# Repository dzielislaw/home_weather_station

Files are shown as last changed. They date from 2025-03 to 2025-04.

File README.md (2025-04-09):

# home-weather-station
## English
This home weather station is a STM32 microcontroller-based device. It performs measurements such as:
 - indor temperature
 - outdoor temperature via external wired probe
 - atmospheric pressure
 - air humidity
 - PM (Particulate Matter) concentration
and moreover it alarms of presence of flammable gases such as propane or buthane.

https://github.com/user-attachments/assets/9bdbaac8-06a2-42ca-afe4-3092634e5976

## Polski
Projekt domowej stacji pogody oparty o wykorzystanie mikrokontrolera STM32G491RE. Wykonuje pomiary takie jak:
- temperatura wewnętrzna
- temperatura zewnętrzna
- ciśnienie atmosferyczne
- wilgotność powietrza
- stężenie pyłu zawieszonego PM1, PM2,5 oraz PM10 (jakości powietrza).
  
ilustracja

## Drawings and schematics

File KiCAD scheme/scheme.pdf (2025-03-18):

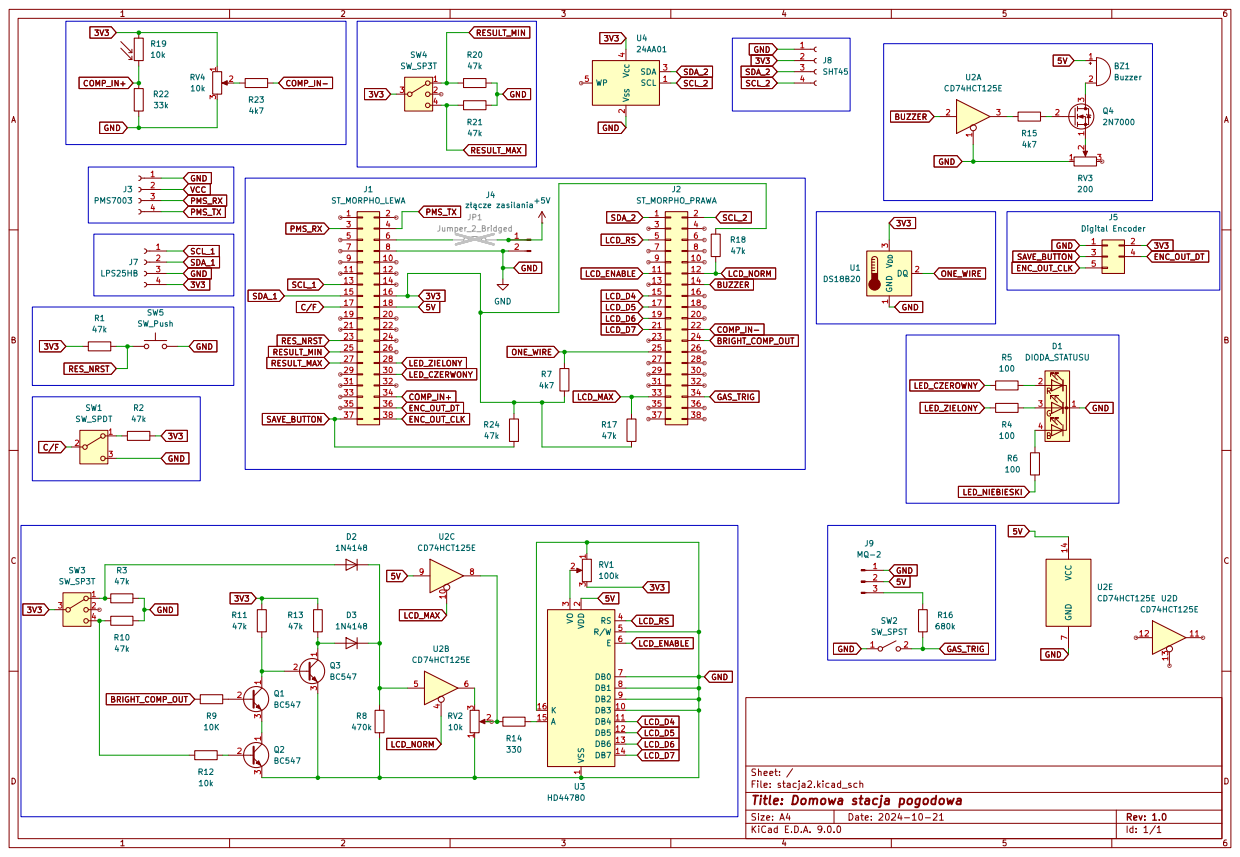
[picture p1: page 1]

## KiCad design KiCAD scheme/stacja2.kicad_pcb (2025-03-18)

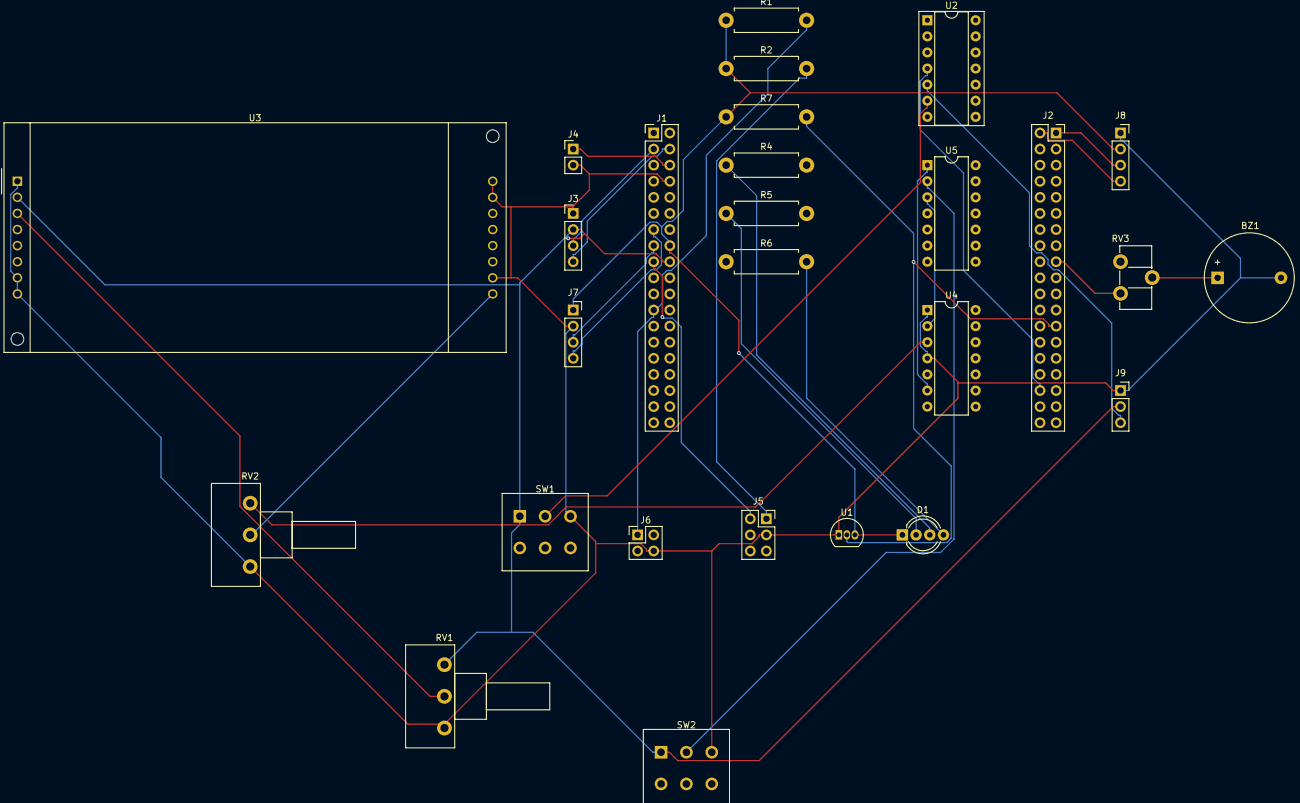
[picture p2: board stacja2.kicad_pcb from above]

Board: 2 copper layers, 27 parts (0 on the bottom side), 36 nets.

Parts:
BZ1: Buzzer; Buzzer_D14mm_H7mm_P10mm
D1: DIODA_STATUSU; LED_D5.0mm-4_RGB_Wide_Pins
J1: ST_MORPHO_LEWA; PinHeader_2x19_P2.54mm_Vertical
J2: ST_MORPHO_PRAWA; PinSocket_2x19_P2.54mm_Vertical
J3: PMS7003; PinHeader_1x04_P2.54mm_Vertical
J4: złącze zasilania; PinHeader_1x02_P2.54mm_Vertical
J5: CELSIUS_FAHRENEIT_SWITCH; PinSocket_2x03_P2.54mm_Vertical
J6: RESET_TACT_SWITCH; PinHeader_2x02_P2.54mm_Vertical
J7: LPS25HB; PinSocket_1x04_P2.54mm_Vertical
J8: SHT35; PinSocket_1x04_P2.54mm_Vertical
J9: MQ-2; PinSocket_1x03_P2.54mm_Vertical
R1, R2: 47k; R_Axial_DIN0411_L9.9mm_D3.6mm_P12.70mm_Horizontal
R4, R5, R6: 460; R_Axial_DIN0411_L9.9mm_D3.6mm_P12.70mm_Horizontal
R7: 4k7; R_Axial_DIN0411_L9.9mm_D3.6mm_P12.70mm_Horizontal
RV1, RV2: 100k; Potentiometer_Piher_T-16H_Single_Horizontal
RV3: 200; Potentiometer_ACP_CA9-H5_Horizontal
SW1, SW2: SW_SPDT; SW_PUSH_E-Switch_FS5700DP_DPDT
U1: DS18B20; TO-92_Inline
U2: 4081; DIP-14_W7.62mm_Socket
U3: HD44780; NHD-0420H1Z
U4: 74AHCT125; DIP-14_W7.62mm
U5: 4071; DIP-14_W7.62mm

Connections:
3V3: D1.1 (A), J1.16, J7.4, J8.2, R1.1, R2.1, R7.1, U1.3 (V_{DD})
5V: J1.18, RV1.3, SW1.1 (A), SW2.1 (A), U3.2 (VDD)
+5V: J1.6, J4.1
BUZZER+: J2.14, RV3.3
C/F: J1.17, J5.2
GAS_TRIG: J2.34, U2.4
GND: BZ1.2 (-), J1.8, J3.1, J4.2, J5.3, J6.4, J7.3, J8.1, J9.1, RV1.1, RV2.1, SW1.3 (C), SW2.3 (C), U1.1 (GND), U3.1 (VSS), U3.5 (R/W), U3.7 (DB0), U3.8 (DB1), U3.9 (DB2), U3.10 (DB3), U3.15 (A), U4.1, U4.4
LCD_D4: J2.15, U3.11 (DB4)
LCD_D5: J2.17, U3.12 (DB5)
LCD_D6: J2.19, U3.13 (DB6)
LCD_D7: J2.21, U3.14 (DB7)
LCD_ENABLE: J2.11, U3.6 (E)
LCD_RS: J2.5, U3.4 (RS)
LED_ZIELONY: J1.28, R4.2
unnamed: BZ1.1 (+), RV3.2
unnamed: D1.4 (BK), R6.2
unnamed: D1.3 (GK), R4.1
unnamed: D1.2 (RK), R5.1
unnamed: J5.1, R2.2
unnamed: J9.3, U2.5
unnamed: RV2.3, U4.3
unnamed: SW1.2 (B), U2.6
unnamed: SW2.2 (B), U5.2
unnamed: RV2.2, U3.16 (K)
unnamed: RV1.2, U3.3 (VO)
unnamed: U4.2, U5.3
unnamed: U4.6, U5.1
ONE_WIRE: J2.25, R7.2, U1.2 (DQ)
PMS_RX: J1.3, J3.3
PMS_TX: J1.4, J3.4
RES_NRST: J1.23, J6.1, R1.2
SCL_1: J1.13, J7.1
SCL_2: J2.2, J8.4
SDA_1: J1.15, J7.2
SDA_2: J2.1, J8.3
VCC: J3.2, J9.2

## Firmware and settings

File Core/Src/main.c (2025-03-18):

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
/* Includes ------------------------------------------------------------------*/
#include "main.h"
#include "comp.h"
#include "dac.h"
#include "i2c.h"
#include "rtc.h"
#include "tim.h"
#include "usart.h"
#include "gpio.h"

/* USER CODE BEGIN Includes */
#include <string.h>
#include <stdio.h>
#include <stdbool.h>
#include "exti.h"
#include "LPS25HB.h"
#include "SHT45.h"
#include "PMS7003.h"
#include "ILI9341.h"
#include "HD44780.h"
#include "RGB565.h"
#include "EPaper.h"
#include "OneWire.h"
#include "DS18B20.h"
#include "EEPROM_24AA01.h"
#include "units.h"
/* USER CODE END Includes */

/* USER CODE BEGIN PTD */
typedef union
{
  int16_t altitude;
  uint8_t memoryImage[2];
} altitudeUnion;

/* USER CODE END PTD */


/* USER CODE BEGIN PV */
 Measurements measurements;
 float tempFromSHT35;
  
bool isWarmingUp = true;
bool isFirstInterrupt = true;
bool shouldLightUpAlarmLED = false;
bool shouldUpdateEeprom = false;
bool shouldEnbleNormBrightness = false;
bool shoulEnable_maxBrightness = false;
bool shouldDelay = true;
bool isPM10Last = true;
altitudeUnion altitude;
/* USER CODE END PV */

void SystemClock_Config(void);
/* USER CODE BEGIN PFP */
void updateMinMaxF(float* value, float* min, float* max);
void updateMinMax(uint16_t* value, uint16_t* min, uint16_t* max);
/* USER CODE END PFP */

/* USER CODE BEGIN 0 */
void handleTimer3PeriodElapsed()
{
  if(isFirstInterrupt == true)
   {
     isFirstInterrupt = false;
   }
   else
   {
     HAL_TIM_Base_Stop_IT(&htim3);
     const char* communicate = "DEBUG: Gas sensor warmed up\r\n";
     HAL_UART_Transmit(&huart4, communicate, strlen(communicate), HAL_MAX_DELAY);
     HAL_GPIO_EXTI_Callback(GPIO_PIN_4);
   }
}

void handleTimer7PeriodElapsed()
{
  if(shouldLightUpAlarmLED == true)
   {
     HAL_TIM_PWM_Start(&htim2, TIM_CHANNEL_2);
     shouldLightUpAlarmLED = false;
   }
   else
   {
     HAL_TIM_PWM_Stop(&htim2, TIM_CHANNEL_2);
     shouldLightUpAlarmLED = true;
   }
}

void HAL_TIM_PeriodElapsedCallback(TIM_HandleTypeDef* htim)
{
  if(htim == &htim3) handleTimer3PeriodElapsed();
  else if(htim == &htim7) handleTimer7PeriodElapsed();
}

void updateMinMaxF(float* value, float* min, float* max)
{
    if(*min > *value) *min = *value;
    if(*max < *value) *max = *value;
}

void updateMinMax(uint16_t* value, uint16_t* min, uint16_t* max)
{
    if(*min > *value) *min = *value;
    if(*max < *value) *max = *value;
}

void convertMeasurementsToCelsius()
{
    measurements.tempUnit = CELSIUS;
    convertFahrenheitToCelsius(&measurements.outdoorTemp);
    convertFahrenheitToCelsius(&tempFromSHT35);
    convertFahrenheitToCelsius(&measurements.temp);
    convertFahrenheitToCelsius(&measurements.minTemp);
    convertFahrenheitToCelsius(&measurements.maxTemp);
    convertFahrenheitToCelsius(&measurements.maxOutdoorTemp);
    convertFahrenheitToCelsius(&measurements.minOutdoorTemp);
}

void convertMeasurementsToFahrenheit()
{
  measurements.tempUnit = FAHRENHEIT;
  convertCelsiusToFahrenheit(&measurements.outdoorTemp);
  convertCelsiusToFahrenheit(&tempFromSHT35);
  convertCelsiusToFahrenheit(&measurements.temp);
  convertCelsiusToFahrenheit(&measurements.minTemp);
  convertCelsiusToFahrenheit(&measurements.maxTemp);
  convertCelsiusToFahrenheit(&measurements.maxOutdoorTemp);
  convertCelsiusToFahrenheit(&measurements.minOutdoorTemp);
}

/* USER CODE END 0 */

/**
  * @brief  The application entry point.
  * @retval int
  */
int main(void)
{

  /* USER CODE BEGIN 1 */
  altitudeUnion tmp;
  /* USER CODE END 1 */

  /* MCU Configuration--------------------------------------------------------*/

  /* Reset of all peripherals, Initializes the Flash interface and the Systick. */
  HAL_Init();

  /* Configure the system clock */
  SystemClock_Config();

  /* Initialize all configured peripherals */
  MX_GPIO_Init();
  MX_UART4_Init();
  MX_I2C1_Init();
  MX_I2C3_Init();
  MX_RTC_Init();
  MX_UART5_Init();
  MX_DAC1_Init();
  MX_TIM2_Init();
  MX_TIM3_Init();
  MX_USART3_UART_Init();
  MX_TIM4_Init();
  MX_TIM7_Init();
  MX_COMP4_Init();
  MX_TIM1_Init();
  MX_TIM20_Init();
  /* USER CODE BEGIN 2 */
  oneWire_HandleTypeDef* hOneWire = &huart3;
  oneWireReset(hOneWire);
  HAL_GPIO_EXTI_Callback(GPIO_PIN_13);
  /* USER CODE END 2 */

  /* Infinite loop */
  /* USER CODE BEGIN WHILE */
  
  //HAL_GPIO_WritePin(LCD_BRIGHT_NORM_GPIO_Port, LCD_BRIGHT_NORM_Pin, GPIO_PIN_RESET);
  
  char communicate[256];
  char unit[5];

  uint32_t brightnessState;
  measurements.tempUnit = CELSIUS;
  
  RTC_DateTypeDef date;
  RTC_TimeTypeDef time;
  
  EEPROM_24AA01_HandleTypeDef eeprom;
  strcpy(eeprom.name, "i2c eeprom");
  eeprom.bus = &hi2c3;
  
  SHT45_HandleTypeDef sht45_Sensor;
  strcpy(sht45_Sensor.name, "indoor humidity sensor");
  sht45_Sensor.bus = &hi2c3;
  
  LPS25HB_HandleTypeDef lps25hb_Sensor;
  strcpy(lps25hb_Sensor.name, "indoor pressure sensor");
  lps25hb_Sensor.bus = &hi2c1;
  lps25hb_Sensor.sensorAltitude = altitude.altitude;
  
  PMS7003_HandleTypeDef pms7003_Sensor;
  strcpy(pms7003_Sensor.name, "indoor air pollution sensor");
  pms7003_Sensor.bus = &huart5;

  DS18B20_HandleTypeDef ds18b20_Sensor;
  strcpy(ds18b20_Sensor.name, "outdoor temperature sensor");
  ds18b20_Sensor.bus = hOneWire;
  uint8_t romCode[] = {0x28, 0x7e, 0x4c, 0x14, 0x00, 0x00, 0x00, 0x6b};
  for(uint8_t i = 0 ; i < 8; i++)
  {
    ds18b20_Sensor.idNumber[i] = romCode[i];
  }
  
  
  HAL_TIM_Base_Start(&htim2);
  HAL_TIM_PWM_Start(&htim2, TIM_CHANNEL_1);
  HAL_TIM_PWM_Start(&htim2, TIM_CHANNEL_2);
  HAL_TIM_Base_Start_IT(&htim3);
  
  HAL_TIM_Encoder_Start(&htim1, TIM_CHANNEL_ALL);
  EEPROM_24AA01_ReadByte(&eeprom, 0x40, &altitude.memoryImage[0]);
  EEPROM_24AA01_ReadByte(&eeprom, 0x41, &altitude.memoryImage[1]);
  __HAL_TIM_SET_COUNTER(&htim1, altitude.altitude * 2);
   
   
  sprintf(communicate, "Weather station hello!\r\n");
  HAL_UART_Transmit(&huart4, communicate, strlen(communicate), HAL_MAX_DELAY);
  SHT45_init(&sht45_Sensor);
  sprintf(communicate, "SHT45 initialization... OK\r\n");
  HAL_UART_Transmit(&huart4, communicate, strlen(communicate), HAL_MAX_DELAY);
  
  if(LPS25HB_init(&lps25hb_Sensor) == -1)
  {
    sprintf(communicate, "LPS25HB pressure sensor initliazation... FAILED\r\n");
    HAL_UART_Transmit(&huart4, communicate, strlen(communicate), HAL_MAX_DELAY);
  }
  else
  {
    sprintf(communicate, "LPS25HB pressure sesnsor initialization... OK\r\n");
    HAL_UART_Transmit(&huart4, communicate, strlen(communicate), HAL_MAX_DELAY);
  }
  
  HD44780_Pin d4;
  d4.Port = LCD_D4_GPIO_Port;
  d4.Pin = LCD_D4_Pin;
  
  HD44780_Pin d5;
  d5.Port = LCD_D5_GPIO_Port;
  d5.Pin = LCD_D5_Pin;
  
  HD44780_Pin d6;
  d6.Port = LCD_D6_GPIO_Port;
  d6.Pin = LCD_D6_Pin;
  
  HD44780_Pin d7;
  d7.Port = LCD_D7_GPIO_Port;
  d7.Pin = LCD_D7_Pin;
  
  HD44780_Pin rs;
  rs.Port = LCD_RS_GPIO_Port;
  rs.Pin = LCD_RS_Pin;
  
  HD44780_Pin enable;
  enable.Port = LCD_ENABLE_GPIO_Port;
  enable.Pin = LCD_ENABLE_Pin;
  
  HD44780_HandleTypeDef hHD44780;
  hHD44780.D4 = d4;
  hHD44780.D5 = d5;
  hHD44780.D6 = d6;
  hHD44780.D7 = d7;
  hHD44780.RS = rs;
  hHD44780.Enable = enable;
  
  HD44780_Init(&hHD44780);
  
  sprintf(communicate, "HD44780 initialization (master only) DONE\r\n");
  HAL_UART_Transmit(&huart4, communicate, strlen(communicate), HAL_MAX_DELAY);
  HAL_GPIO_WritePin(LCD_BRIGHT_NORM_GPIO_Port, LCD_BRIGHT_NORM_Pin, GPIO_PIN_RESET);
  
  char lcdString[21];
  HAL_COMP_Start(&hcomp4);
  HAL_DAC_Start(&hdac1, DAC_CHANNEL_1);
   HAL_DAC_SetValue(&hdac1, DAC_CHANNEL_1, DAC_ALIGN_12B_R, 02570); // dobrane empirycznie
  while (1)
  {         
    brightnessState = HAL_COMP_GetOutputLevel(&hcomp4);
    //HAL_COMP_Stop(&hcomp4);
    //HAL_DAC_Stop(&hdac1, DAC_CHANNEL_1);
    PMS7003_getResults(&pms7003_Sensor, &measurements.pm1_0, &measurements.pm2_5, &measurements.pm10);
    updateMinMax(&measurements.pm1_0, &measurements.minPm1_0, &measurements.maxPm1_0);
      updateMinMax(&measurements.pm2_5, &measurements.minPm2_5, &measurements.maxPm2_5);
      updateMinMax(&measurements.pm10, &measurements.minPm10, &measurements.maxPm10);
      
      LPS25HB_performMeasurement(&lps25hb_Sensor);
      measurements.temp = LPS25HB_getTemp(&lps25hb_Sensor, measurements.tempUnit);
      updateMinMaxF(&measurements.temp, &measurements.minTemp, &measurements.maxTemp);

      altitude.altitude = (int16_t) (__HAL_TIM_GET_COUNTER(&htim1) / 2);
      if(altitude.altitude > 30000) 
      {
        altitude.altitude -= 32768;
      }
      lps25hb_Sensor.sensorAltitude = altitude.altitude;
      measurements.pressure = LPS25HB_getPressureIn_hPa(&lps25hb_Sensor);
      updateMinMaxF(&measurements.pressure, &measurements.minPressure, &measurements.maxPressure);
      
      DS18B20_convertT(&ds18b20_Sensor);
      HAL_Delay(750);
      DS18B20_getResult(&ds18b20_Sensor, &measurements.outdoorTemp, measurements.tempUnit);
      HAL_Delay(10);
      updateMinMaxF(&measurements.outdoorTemp, &measurements.minOutdoorTemp, &measurements.maxOutdoorTemp);
      
      HAL_RTC_GetTime(&hrtc, &time, RTC_FORMAT_BIN);
      HAL_RTC_GetDate(&hrtc, &date, RTC_FORMAT_BIN);

      SHT45_getResults(&sht45_Sensor, &tempFromSHT35, measurements.tempUnit, &measurements.humidity);
      updateMinMaxF(&measurements.humidity, &measurements.minHumidity, &measurements.maxHumidity);
      

      if(HAL_GPIO_ReadPin(GPIOA, TEMP_UNIT_INPUT_Pin) == GPIO_PIN_RESET && measurements.tempUnit == CELSIUS)
      {
        convertMeasurementsToFahrenheit();
      }
      else if (HAL_GPIO_ReadPin(GPIOA, TEMP_UNIT_INPUT_Pin) == GPIO_PIN_SET && measurements.tempUnit == FAHRENHEIT)
      {
        convertMeasurementsToCelsius();
      }
      sprintf(unit, "%c", getTemperatureUnitSymbol(measurements.tempUnit));
      sprintf(communicate, "Raport na: %02d-%02d-%4d %02d:%02d:%02d\r\n",  date.Date, date.Month, date.Year + 2000, time.Hours, time.Minutes, time.Seconds);
      HAL_UART_Transmit(&huart4, communicate, strlen(communicate), HAL_MAX_DELAY);
      if(brightnessState == COMP_OUTPUT_LEVEL_HIGH)
      {
        sprintf(communicate, "Jest jasno\r\n");
      }
      else
      {
        sprintf(communicate, "Jest ciemno\r\n");
      }
      
      HAL_UART_Transmit(&huart4, communicate, strlen(communicate), HAL_MAX_DELAY);
      sprintf(communicate, "Temperatura wynosi (LPS25HB) %.2f \xC2\xB0%s / (SHT35) %.2f \xC2\xB0%s\tmin: %.2f \xC2\xB0%s\tmax: %.2f \xC2\xB0%s\r\n", measurements.temp, unit, tempFromSHT35, unit, measurements.minTemp, unit, measurements.maxTemp, unit);
      HAL_UART_Transmit(&huart4, communicate, strlen(communicate), HAL_MAX_DELAY);
      sprintf(communicate, "Temperatura na zewnatrz wynosi %.2f \xC2\xB0%s\tmin: %.2f \xC2\xB0%s\tmax: %.2f \xC2\xB0%s\r\n", measurements.outdoorTemp, unit, measurements.minOutdoorTemp, unit, measurements.maxOutdoorTemp, unit);
      HAL_UART_Transmit(&huart4, communicate, strlen(communicate), HAL_MAX_DELAY);
      sprintf(communicate, "Cisnienie wynosi: %.2f hPa\tmin: %.2f hPa\tmax: %.2f hPa\r\n", measurements.pressure, measurements.minPressure, measurements.maxPressure);
      HAL_UART_Transmit(&huart4, communicate, strlen(communicate), HAL_MAX_DELAY);
      sprintf(communicate, "Wilgotnosc wzgledna wynosi %.1f RH\tmin: %.1f RH\tmax: %.1f RH\r\n", measurements.humidity, measurements.minHumidity, measurements.maxHumidity);
      HAL_UART_Transmit(&huart4, communicate, strlen(communicate), HAL_MAX_DELAY);
      sprintf(communicate, "Stezenie pylu zawieszonego PM 1.0 wynosi %hu ug/m3\tmin: %hu ug/m3\tmax: %hu ug/m3\r\nStezenie pylu zawieszonego PM 2.5 wynosi %hu ug/m3\tmin: %hu ug/m3\tmax: %hu ug/m3\r\nStezenie pylu zawieszonego PM 10 wynosi %hu ug/m3\tmin: %hu ug/m3\tmax: %hu ug/m3\r\n\r\n",
               measurements.pm1_0, measurements.minPm1_0, measurements.maxPm1_0, measurements.pm2_5, measurements.minPm2_5, measurements.maxPm2_5, measurements.pm10, measurements.minPm10, measurements.maxPm10);
      HAL_UART_Transmit(&huart4, communicate, strlen(communicate), HAL_MAX_DELAY);
      
      sprintf(communicate, "%.2f %.2f %.1f %hu %hu %hu \r\n", measurements.temp, measurements.pressure, measurements.humidity, measurements.pm1_0, measurements.pm2_5, measurements.pm10);
      HAL_UART_Transmit(&huart5, communicate, strlen(communicate), HAL_MAX_DELAY);
      
      if(shouldEnbleNormBrightness || shoulEnable_maxBrightness){
        clearDisplay(&hHD44780);
        HAL_Delay(5);
        if(shoulEnable_maxBrightness){
          HAL_GPIO_WritePin(LCD_BRIGHT_MAX_GPIO_Port, LCD_BRIGHT_MAX_Pin, GPIO_PIN_RESET);
          HD44780_SetDDRAMAdress(&hHD44780, 0);
          sprintf(lcdString, "ALARM, GAZY PALNE!");
          HD44780_DisplayString(&hHD44780, lcdString);
          shoulEnable_maxBrightness = false;
          while (shouldEnbleNormBrightness == false){};
          HAL_Delay(5);
        } 
         HAL_GPIO_WritePin(LCD_BRIGHT_NORM_GPIO_Port, LCD_BRIGHT_NORM_Pin, GPIO_PIN_RESET);
         shouldEnbleNormBrightness = false;
         clearDisplay(&hHD44780);
      }
      
      if(HAL_GPIO_ReadPin(MIN_INPUT_GPIO_Port, MIN_INPUT_Pin) == GPIO_PIN_RESET){
        measurements.pressure = measurements.minPressure;
        measurements.humidity = measurements.minHumidity;
        measurements.pm10 = measurements.minPm10;
        measurements.pm2_5 = measurements.minPm2_5;
        measurements.pm1_0 = measurements.minPm1_0;
        measurements.outdoorTemp = measurements.minOutdoorTemp;
        measurements.temp = measurements.minTemp;
      }
        else if(HAL_GPIO_ReadPin(MAKS_INPUT_GPIO_Port, MAKS_INPUT_Pin) == GPIO_PIN_RESET){
        measurements.pressure = measurements.maxPressure;
        measurements.humidity = measurements.maxHumidity;
        measurements.pm10 = measurements.maxPm10;
        measurements.pm2_5 = measurements.maxPm2_5;
        measurements.pm1_0 = measurements.maxPm1_0;
        measurements.outdoorTemp = measurements.maxOutdoorTemp;
        measurements.temp = measurements.maxTemp;
      }
      
      HD44780_SetDDRAMAdress(&hHD44780, 0);
      sprintf(lcdString, "%c%.1f\xDF%c %.1f\xDF%c", (tempFromSHT35 >= 0)? ' ' : '-', tempFromSHT35, getTemperatureUnitSymbol(measurements.tempUnit), measurements.outdoorTemp, getTemperatureUnitSymbol(measurements.tempUnit));
      HD44780_DisplayString(&hHD44780, lcdString);
      
      HD44780_SetDDRAMAdress(&hHD44780, 0x40);
      if(measurements.pressure < 1000){
        sprintf(lcdString, " %d hPa %d m.n.p.m.", (uint16_t) measurements.pressure, altitude.altitude);
      }
      else{
        sprintf(lcdString, "%d hPa %d m.n.p.m.", (uint16_t) measurements.pressure,  altitude.altitude);
      }
      HD44780_DisplayString(&hHD44780, lcdString);
      
      HD44780_SetDDRAMAdress(&hHD44780, 0x14);
      sprintf(lcdString, "PM1 %d ug/m3 %d%% RH", measurements.pm1_0, (uint16_t) measurements.humidity);
      HD44780_DisplayString(&hHD44780, lcdString);
      
      HD44780_SetDDRAMAdress(&hHD44780, 0x54);
      if(isPM10Last){
        sprintf(lcdString, "PM2.5 %d ug/m3", measurements.pm2_5);
      }
      else{
        sprintf(lcdString, "PM10 %d ug/m3", measurements.pm10);
      }
      HD44780_DisplayString(&hHD44780, lcdString); 
      isPM10Last = !isPM10Last;
      
      if(shouldUpdateEeprom)
      {
        shouldUpdateEeprom = false;
        EEPROM_24AA01_ReadByte(&eeprom, 0x40, &tmp.memoryImage[0]);
        EEPROM_24AA01_ReadByte(&eeprom, 0x41, &tmp.memoryImage[1]);
        if(tmp.altitude != altitude.altitude)
        {
          EEPROM_24AA01_WriteByte(&eeprom, 0x40, &altitude.memoryImage[0]);
          EEPROM_24AA01_WriteByte(&eeprom, 0x41, &altitude.memoryImage[1]);
          sprintf(communicate, "Altitude %d saved to eeprom\r\n", altitude.altitude);
          HAL_UART_Transmit(&huart4, communicate, strlen(communicate), HAL_MAX_DELAY);
        }
      }
      
      HAL_Delay(250);
    /* USER CODE END WHILE */

    /* USER CODE BEGIN 3 */
  }
  /* USER CODE END 3 */
}

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


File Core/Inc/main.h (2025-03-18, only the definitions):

#define MAX_INPUT_Pin GPIO_PIN_14
#define MAX_INPUT_GPIO_Port GPIOC
#define MAX_INPU_Pin GPIO_PIN_15
#define MAX_INPU_GPIO_Port GPIOC
#define MIN_INPUT_Pin GPIO_PIN_4
#define MIN_INPUT_GPIO_Port GPIOA
#define LCD_ENABLE_Pin GPIO_PIN_5
#define LCD_ENABLE_GPIO_Port GPIOA
#define LCD_D4_Pin GPIO_PIN_7
#define LCD_D4_GPIO_Port GPIOA
#define LCD_D6_Pin GPIO_PIN_7
#define LCD_D6_GPIO_Port GPIOC
#define LCD_D7_Pin GPIO_PIN_9
#define LCD_D7_GPIO_Port GPIOA
#define LCD_BRIGHT_MAX_Pin GPIO_PIN_10
#define LCD_BRIGHT_MAX_GPIO_Port GPIOA
#define LCD_BRIGHT_NORM_Pin GPIO_PIN_12
#define LCD_BRIGHT_NORM_GPIO_Port GPIOA
#define TEMP_UNIT_INPUT_Pin GPIO_PIN_15
#define TEMP_UNIT_INPUT_GPIO_Port GPIOA
#define LCD_D5_Pin GPIO_PIN_6
#define LCD_D5_GPIO_Port GPIOB
#define MAKS_INPUT_Pin GPIO_PIN_7
#define MAKS_INPUT_GPIO_Port GPIOB
#define LCD_RS_Pin GPIO_PIN_9
#define LCD_RS_GPIO_Port GPIOB

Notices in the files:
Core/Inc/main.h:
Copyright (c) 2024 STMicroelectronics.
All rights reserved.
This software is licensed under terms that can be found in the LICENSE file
